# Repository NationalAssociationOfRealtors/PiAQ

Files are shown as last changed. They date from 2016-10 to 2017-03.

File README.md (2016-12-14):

#PiAQ - Open Source Indoor Air Quality Sensor
An open hardware and software indoor air quality Raspberry Pi HAT provided by the [National Association of REALTORS](http://realtor.org) and [CRT Labs](https://crtlabs.org).

The board comes in two form factors. One dedicated for the Raspberry Pi - [PiAQ](http://piaq.io)

<p align="center">
  <a href="http://piaq.io">CRT Sensor Board</a>
</p>

Measurement Points:

* Temperature (SHT31)
* Relative Humidity (SHT31)
* VOC (Volatile Organic Compounds) (IAQ Core)
* Derived CO2 (IAQ Core)
* Barometric Pressure (MPL3115A2)
* Light Intensity (TSL2561)
* CO Concentration (MiCS-4154)
* NO2 Concentration (MiCS-4154)
* Sound Intensity (ADMP401)

Connectivity:

* FSK (RFM69HW 433/915MHz)
* WiFi (Particle Photon)
* Cellular (Particle Electron) (Coming soon)
* LoRa (Coming Soon)

License:
Apache License Version 2.0

For information on the standalone air quality sensor, <a href="https://github.com/NationalAssociationOfRealtors/IndoorAirQualitySensor">click here.
<p align="center">
  CRT Sensor Board
</p>
</a>

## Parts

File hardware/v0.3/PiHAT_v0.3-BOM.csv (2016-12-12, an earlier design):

Qty | Value | Device | Package | Parts | Description | MPN
3 |  | LEDCHIPLED_0805 | CHIPLED_0805 | LED1- LED2- LED3 | LED | LTST-C170TBKT
8 | 0.1uF | CAP0805 | 805 | C3- C4- C5- C7- C10- C11- C12- C15 | Capacitor | CC0603KRX7R7BB104
1 | 1.5K | RESISTOR0805-RES | 805 | R3 | Resistor | RT0805BRD071K5L
2 | 100K | RESISTOR0805-RES | 805 | R8- R9 | Resistor | RC0805FR-07100KL
1 | 100pF | CAP0805 | 805 | C2 | Capacitor | CC0805JRNPO9BN101
5 | 10K | RESISTOR0805-RES | 805 | R1- R5- R6- R7- R13 | Resistor | RC0805JR-0710KL
1 | 16MHZ | RESONATOR16MHZ | RESONATOR-SMD | Y1 | Resonator | CSTCE16M0V53-R0
1 | 1uF | CAP0805 | 805 | C9 | Capacitor | CC0805KKX7R7BB105
1 | 4.7uF | CAP0805 | 805 | C8 | Capacitor | CC0805KKX5R8BB475
3 | 47 | RESISTOR0805-RES | 805 | R2- R4- R10 | Resistor | RC0805JR-0747RL
1 | ADMP401 | ADMP401 | ADMP401 | U6 | Omnidirection bottom-port MEMS microphone | INMP401ACEZ-R7
1 | ATMEGA328P | ATMEGA328P_TQFP | TQFP32-08 | U1 | MCU | ATMEGA328PB-AU
1 | BMP280 | BMP280 | BMP280 | IC1 | Barometric pressure sensor | BMP280
1 | CCS811 | CCS811-I2C | LGA | U8 | Digital Gas Sensor | CCS811
1 | OPA344 | OPA344 | SOT23-5 | U3 | Single gate rail-to-rail output op-amp. Inputs extend 300mV past rails. | OPA344NA/3K
1 | SHT31/35 | SHT31-DIS | SHT3X | U7 | Temperature and Humidity | SHT31-DIS-B
1 | TAC_SWITCHSMD | TAC_SWITCHSMD | TACTILE-SWITCH-SMD | RESET | Momentary Switch | PTS525SM15SMTR2 LFS
1 | TSL2561 | TSL2561FN | FN-6 | U2 | TSL2561 illumination sensor | TSL2561FN

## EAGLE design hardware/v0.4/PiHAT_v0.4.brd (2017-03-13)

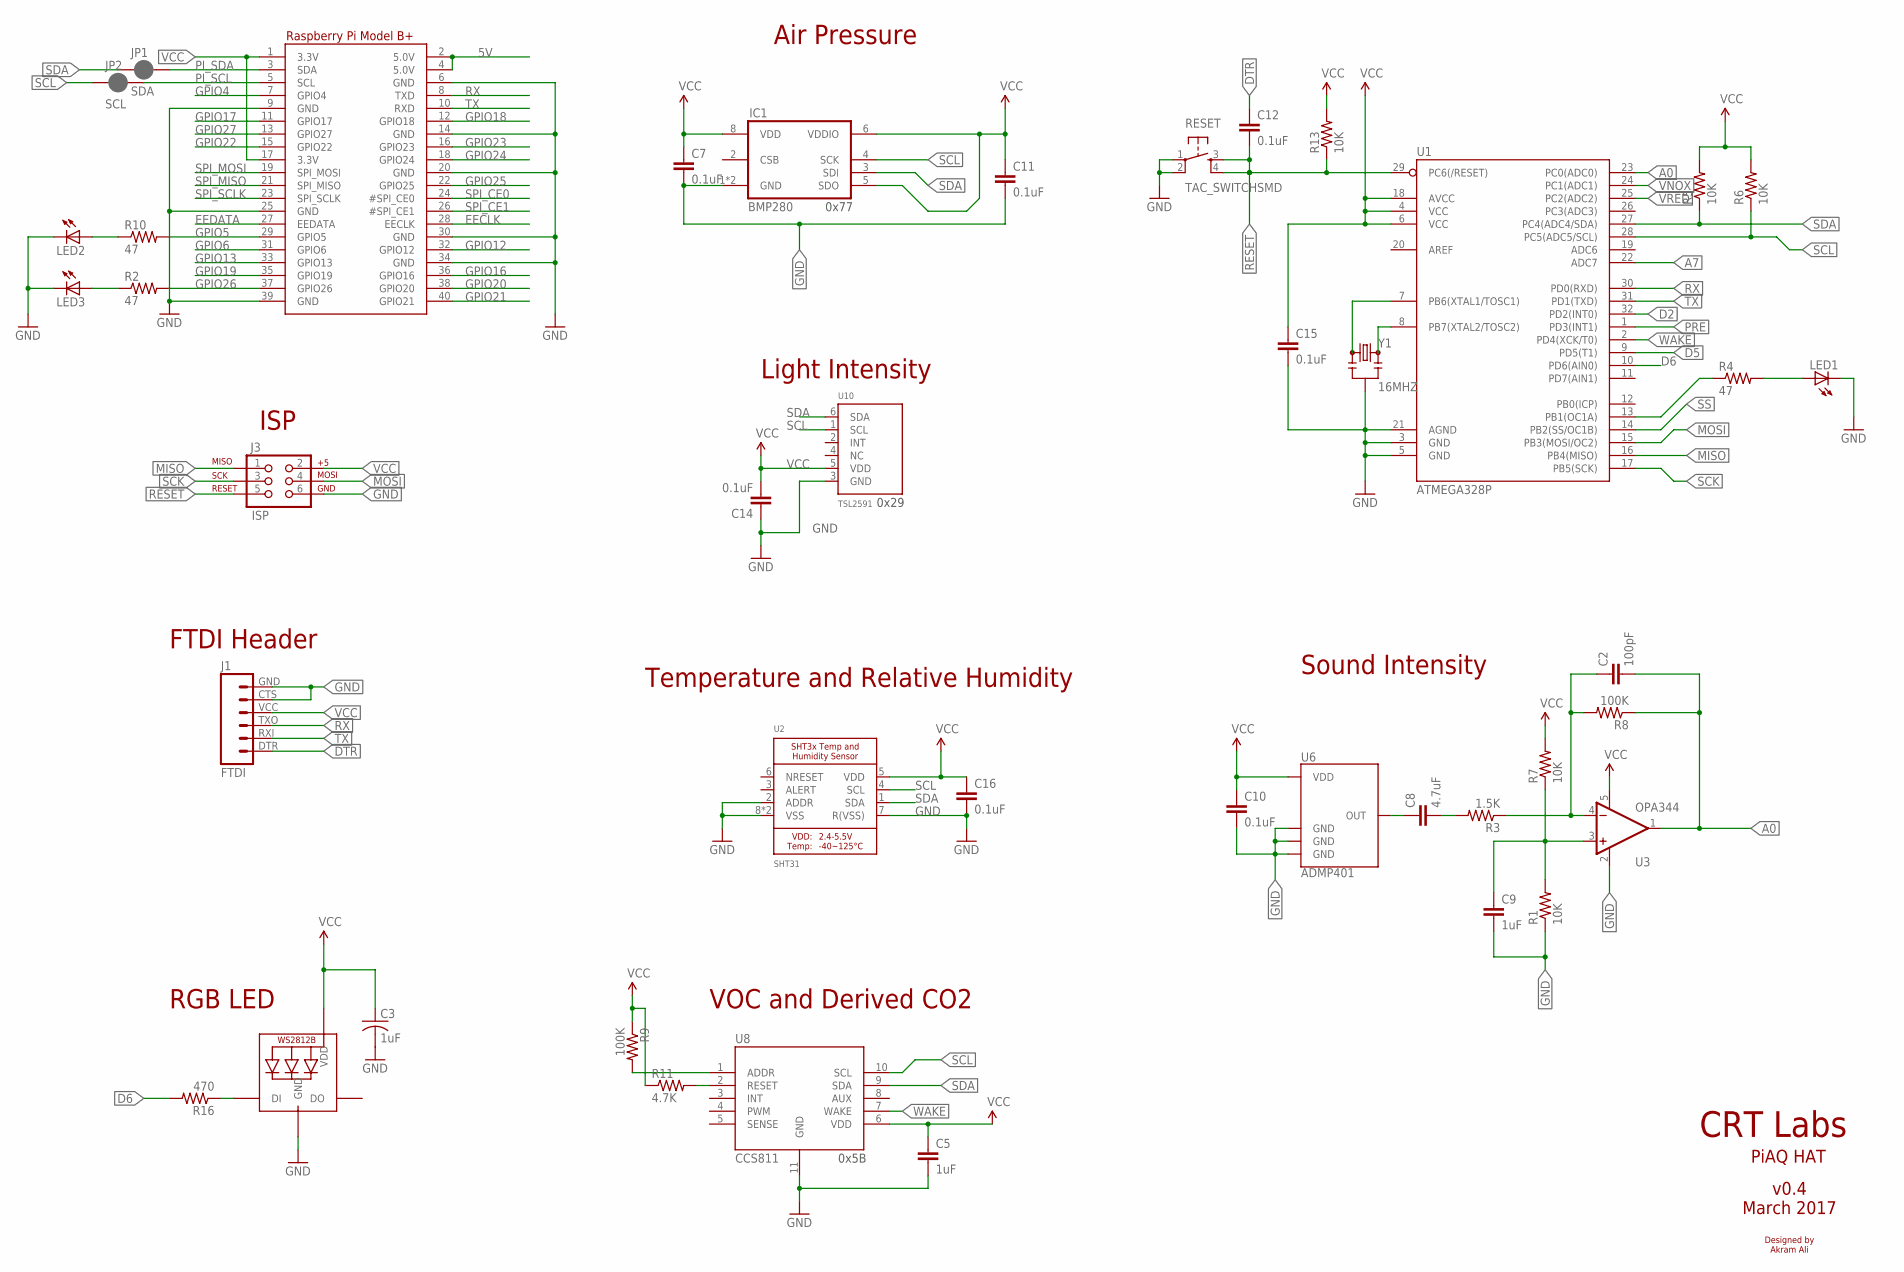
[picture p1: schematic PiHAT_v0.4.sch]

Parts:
C2: 100pF; 0805; MPN CC0805JRNPO9BN101
C3: 1uF; C0603K; MPN CC0805ZRY5V8BB105
C5: 1uF; 0805; MPN CC0603KRX7R7BB104
C7, C10, C11, C12, C15: 0.1uF; 0805; MPN CC0603KRX7R7BB104
C8: 4.7uF; 0805; MPN CC0805KKX5R8BB475
C9: 1uF; 0805; MPN CC0805KKX7R7BB105
C14, C16: 0.1uF; 0805; MPN CC0805KRX7R9BB104
IC1: BMP280; MPN BMP280
J1: FTDI; FTDI_BASIC
J3: ISP; 2X3
JP1: SDA; PAD-JUMPER-2-NC_BY_PASTE_YES_SILK_FULL_BOX
JP2: SCL; PAD-JUMPER-2-NC_BY_PASTE_YES_SILK_FULL_BOX
LED1, LED2, LED3: LEDCHIPLED_0805; CHIPLED_0805; MPN LTST-C170TBKT
R1, R5, R6, R7, R13: 10K; 0805; MPN RC0805JR-0710KL
R2, R4, R10: 47; 0805; MPN RC0805JR-0747RL
R3: 1.5K; 0805; MPN RT0805BRD071K5L
R8, R9: 100K; 0805; MPN RC0805FR-07100KL
R11: 4.7K; 0805; MPN RC0805FR-07100KL
R16: 470; R0603; MPN RC0805FR-07470RL
RESET: TAC_SWITCHSMD; TACTILE-SWITCH-SMD; MPN PTS525SM15SMTR2 LFS
RGBLED: WS2812B3535; LED3535; MPN SK6812 mini
RPI1: RASPBERRYPI_BPLUS_HATSLOTS; PI_HAT_SLOTS
U1: ATMEGA328P; TQFP32-08; MPN ATMEGA328PB-AU
U2: SHT31; SHT3X; MPN SHT35-DIS-B
U3: OPA344; SOT23-5; MPN OPA344NA/3K
U6: ADMP401; MPN INMP401ACEZ-R7
U8: CCS811; LGA; MPN CCS811
U10: TSL2591; DFN6_TAOS; MPN TSL25911FN
Y1: 16MHZ; RESONATOR-SMD; MPN CSTCE16M0V53-R0

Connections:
5V: RPI1.2 (5.0V), RPI1.4 (5.0V)
A0: C2.2, R8.1, U1.23 (PC0(ADC0)), U3.1 (OUT)
A7: U1.22 (ADC7)
D2: U1.32 (PD2(INT0))
D5: U1.9 (PD5(T1))
D6: R16.2, U1.10 (PD6(AIN0))
DTR: C12.1, J1.DTR (1)
EECLK: RPI1.28 (EECLK)
EEDATA: RPI1.27 (EEDATA)
GND: C3.2, C5.2, C7.2, C9.2, C10.2, C11.2, C14.1, C15.2, C16.2, IC1.1 (GND), IC1.7 (GND), J1.CTS (5), J1.GND (6), J3.6, LED1.C, LED2.C, LED3.C, R1.1, RESET.1, RESET.2, RGBLED.4 (GND), RPI1.6 (GND), RPI1.9 (GND), RPI1.14 (GND), RPI1.20 (GND), RPI1.25 (GND), RPI1.30 (GND), RPI1.34 (GND), RPI1.39 (GND), U1.3 (GND), U1.5 (GND), U1.21 (AGND), U2.2 (ADDR), U2.7 (R(VSS)), U2.8 (VSS), U2.THERMAL (VSS), U3.2 (V-), U6.2 (GND), U6.4 (GND), U6.6 (GND), U8.11 (GND), U10.3 (GND), Y1.2
GPIO4: RPI1.7 (GPIO4)
GPIO5: R10.2, RPI1.29 (GPIO5)
GPIO6: RPI1.31 (GPIO6)
GPIO12: RPI1.32 (GPIO12)
GPIO13: RPI1.33 (GPIO13)
GPIO16: RPI1.36 (GPIO16)
GPIO17: RPI1.11 (GPIO17)
GPIO18: RPI1.12 (GPIO18)
GPIO19: RPI1.35 (GPIO19)
GPIO20: RPI1.38 (GPIO20)
GPIO21: RPI1.40 (GPIO21)
GPIO22: RPI1.15 (GPIO22)
GPIO23: RPI1.16 (GPIO23)
GPIO24: RPI1.18 (GPIO24)
GPIO25: RPI1.22 (GPIO25)
GPIO26: R2.2, RPI1.37 (GPIO26)
GPIO27: RPI1.13 (GPIO27)
MISO: J3.1, U1.16 (PB4(MISO))
MOSI: J3.4, U1.15 (PB3(MOSI/OC2))
unnamed: LED3.A, R2.1
unnamed: R4.1, U1.13 (PB1(OC1A))
unnamed: LED1.A, R4.2
unnamed: U1.8 (PB7(XTAL2/TOSC2)), Y1.3
unnamed: U1.7 (PB6(XTAL1/TOSC1)), Y1.1
unnamed: LED2.A, R10.1
unnamed: C8.1, U6.1 (OUT)
unnamed: R11.2, U8.2 (RESET)
unnamed: C8.2, R3.2
unnamed: C2.1, R3.1, R8.2, U3.4 (-IN)
unnamed: C9.1, R1.2, R7.1, U3.3 (+IN)
unnamed: R16.1, RGBLED.1 (DI)
unnamed: R9.2, U8.1 (ADDR)
PI_SCL: JP2.2, RPI1.5 (SCL)
PI_SDA: JP1.2, RPI1.3 (SDA)
PRE: U1.1 (PD3(INT1))
RESET: C12.2, J3.5, R13.1, RESET.3, RESET.4, U1.29 (PC6(/RESET))
RX: J1.TXO (3), RPI1.8 (TXD), U1.30 (PD0(RXD))
SCK: J3.3, U1.17 (PB5(SCK))
SCL: IC1.4 (SCK), JP2.1, R6.1, U1.28 (PC5(ADC5/SCL)), U2.4 (SCL), U8.10 (SCL), U10.1 (SCL)
SDA: IC1.3 (SDI), JP1.1, R5.1, U1.27 (PC4(ADC4/SDA)), U2.1 (SDA), U8.9 (SDA), U10.6 (SDA)
SPI_CE0: RPI1.24 (#SPI_CE0)
SPI_CE1: RPI1.26 (#SPI_CE1)
SPI_MISO: RPI1.21 (SPI_MISO)
SPI_MOSI: RPI1.19 (SPI_MOSI)
SPI_SCLK: RPI1.23 (SPI_SCLK)
SS: U1.14 (PB2(SS/OC1B))
TX: J1.RXI (2), RPI1.10 (RXD), U1.31 (PD1(TXD))
VCC: C3.1, C5.1, C7.1, C10.1, C11.1, C14.2, C15.1, C16.1, IC1.5 (SDO), IC1.6 (VDDIO), IC1.8 (VDD), J1.VCC (4), J3.2, R5.2, R6.2, R7.2, R9.1, R11.1, R13.2, RGBLED.2 (VDD), RPI1.1 (3.3V), RPI1.17 (3.3V), U1.4 (VCC), U1.6 (VCC), U1.18 (AVCC), U2.5 (VDD), U3.5 (V+), U6.5 (VDD), U8.6 (VDD), U10.5 (VDD)
VNOX: U1.24 (PC1(ADC1))
VRED: U1.25 (PC2(ADC2))
WAKE: U1.2 (PD4(XCK/T0)), U8.7 (WAKE)

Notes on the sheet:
VOC and Derived CO2
Air Pressure
Sound Intensity
Temperature and Relative Humidity
ISP
CRT Labs
PiAQ HAT
v0.4 March 2017
Designed by Akram Ali
0x5B
FTDI Header
0x77
Light Intensity
0x29
RGB LED

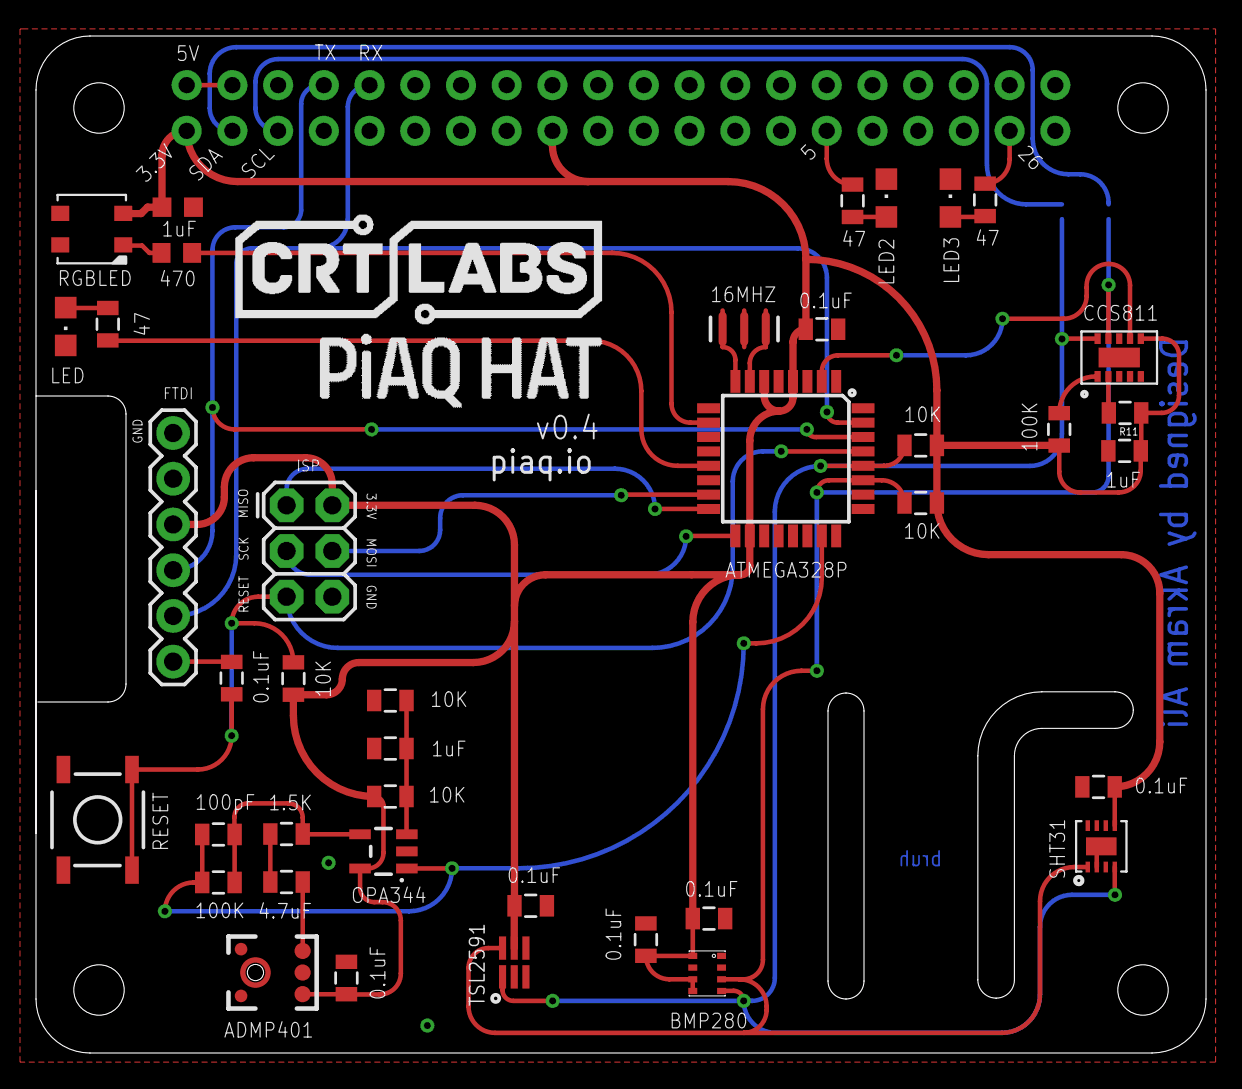
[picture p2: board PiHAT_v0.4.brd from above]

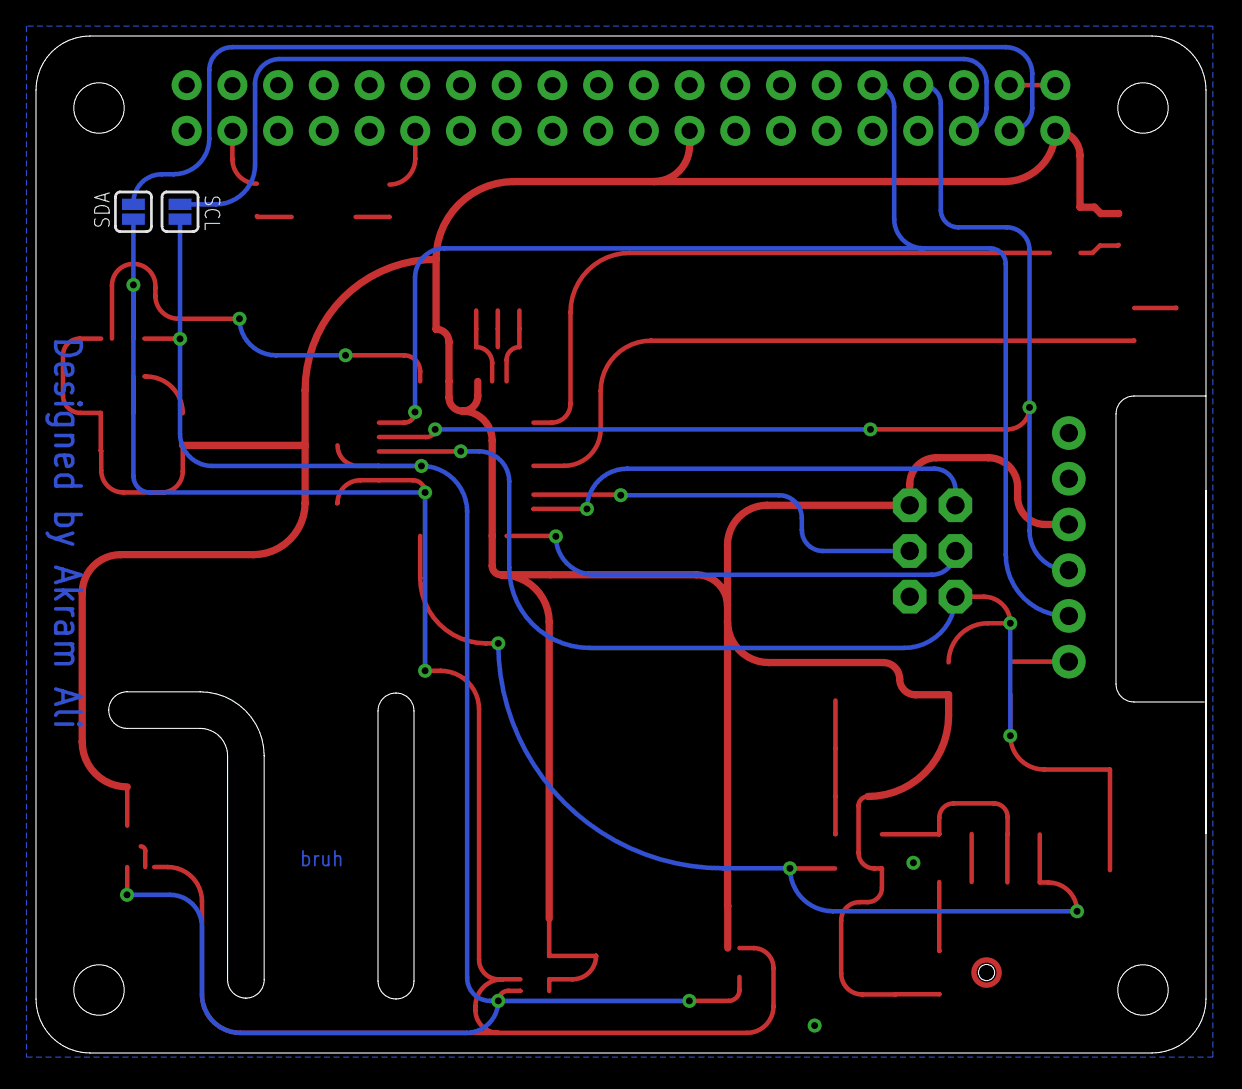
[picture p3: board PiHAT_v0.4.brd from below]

Board: 2 copper layers, 65.0 x 56.5 mm, 43 parts (2 on the bottom side), 32 nets.

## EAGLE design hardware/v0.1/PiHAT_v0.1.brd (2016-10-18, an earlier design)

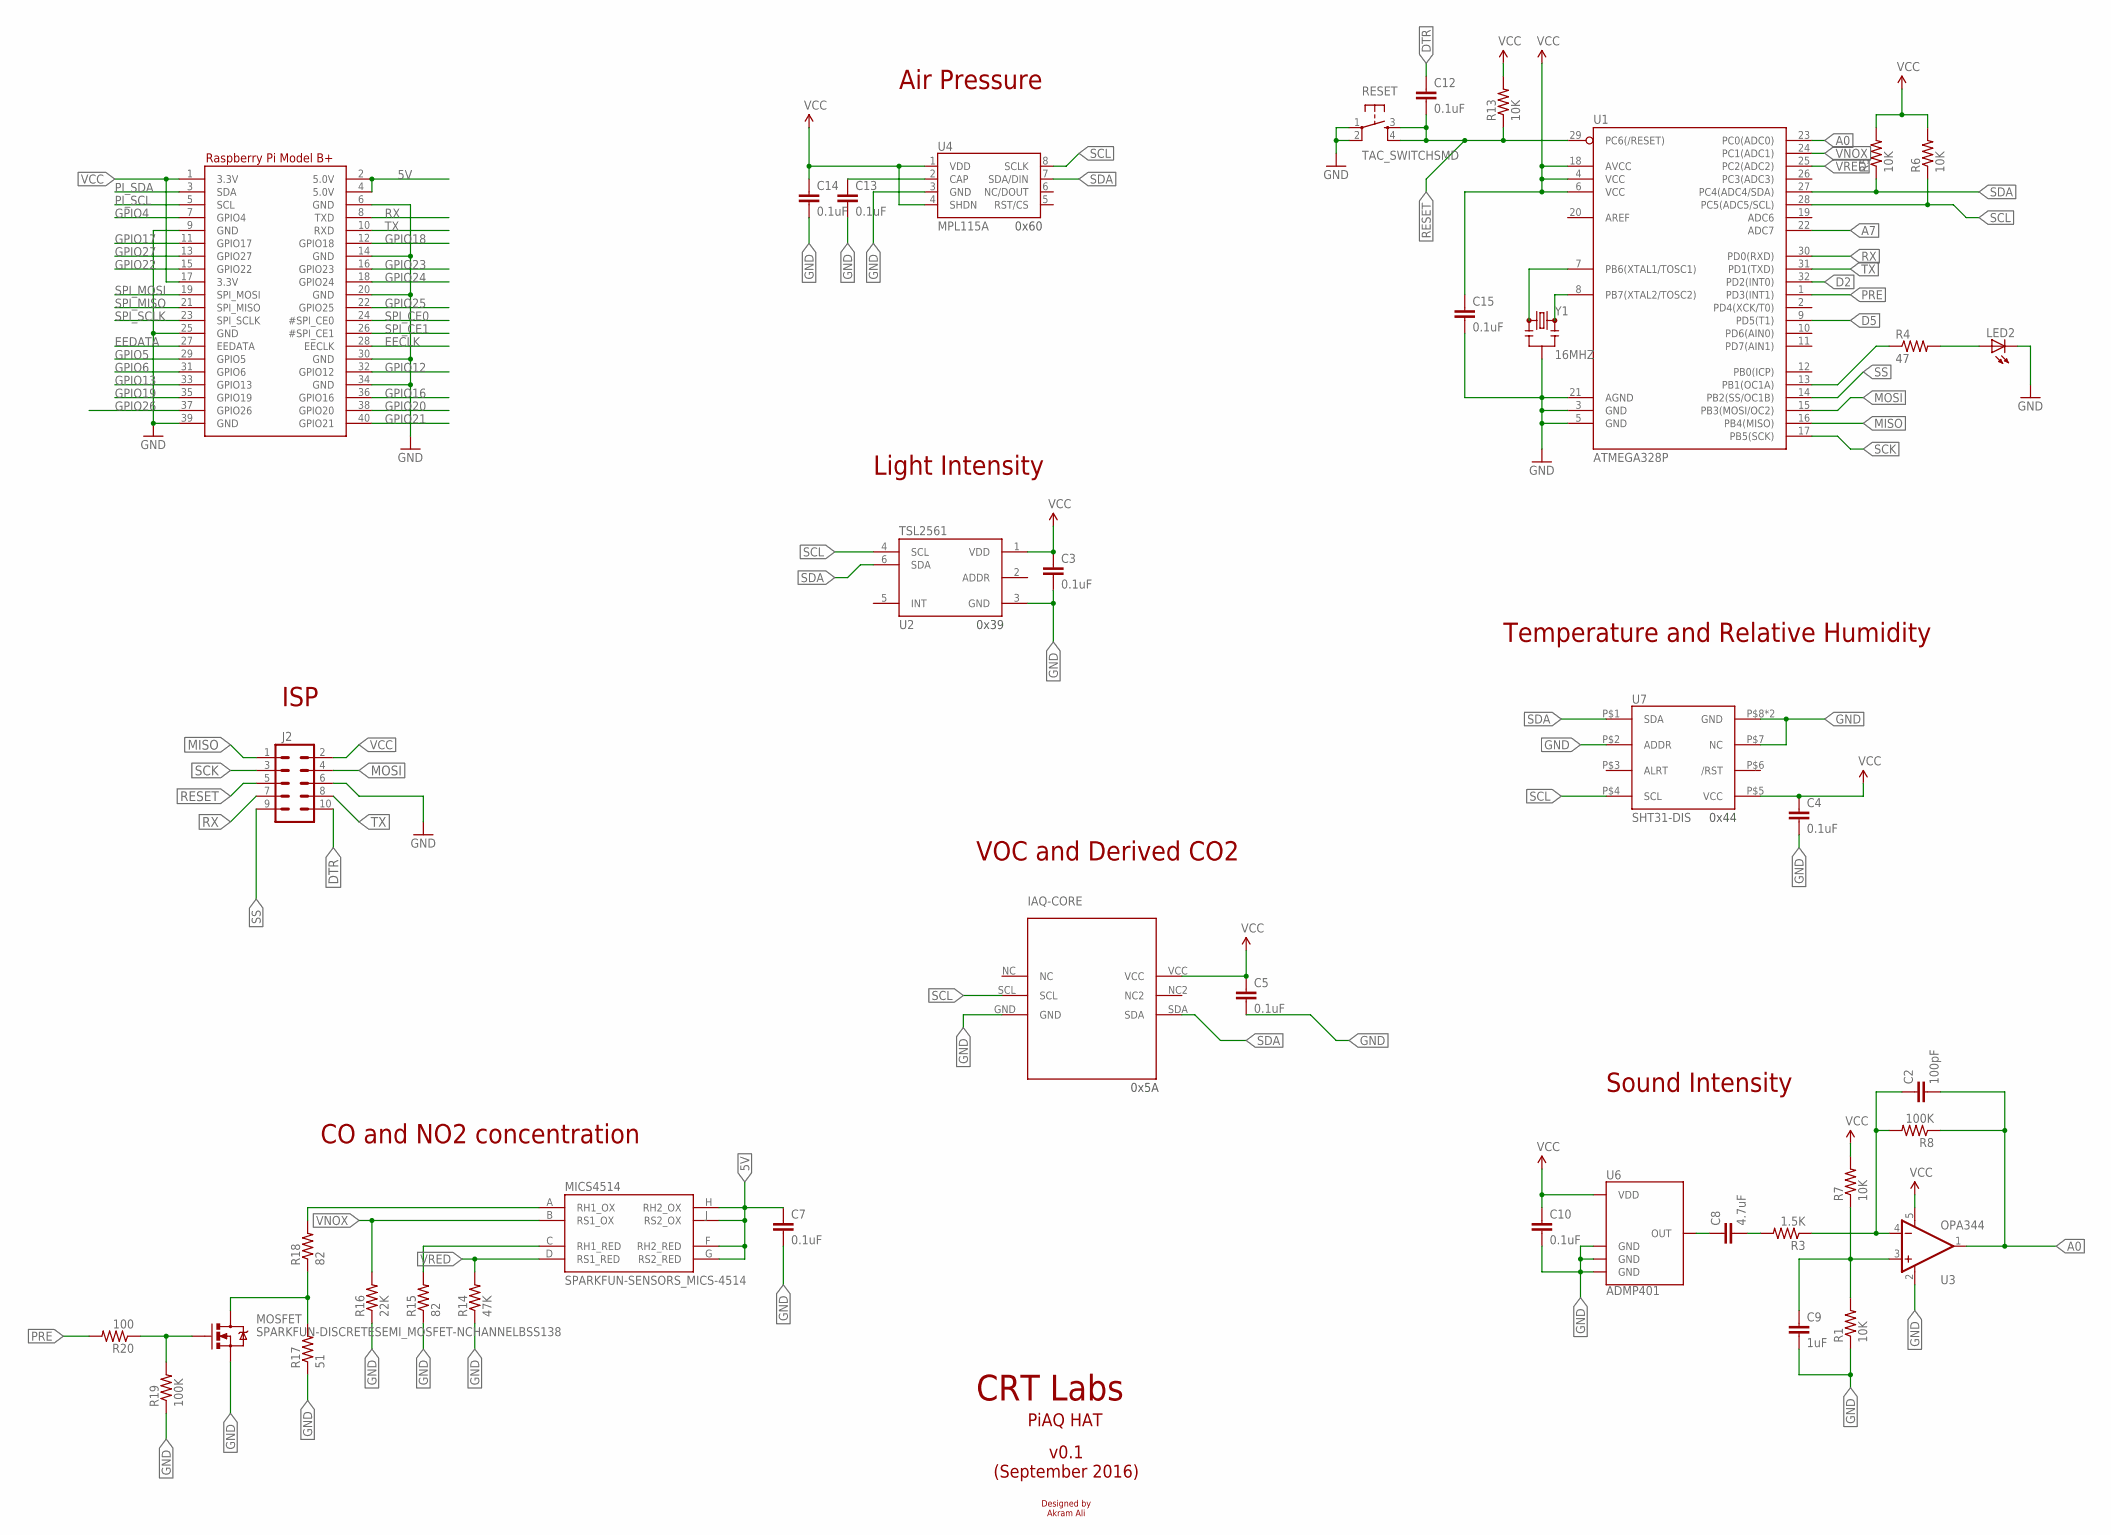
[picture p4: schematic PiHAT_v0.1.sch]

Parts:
C2: 100pF; 0805; DIGIKEY# 311-1111-1-ND
C3, C4, C5, C7, C10, C12, C13, C14, C15: 0.1uF; 0805; DIGIKEY# 311-1088-1-ND
C8: 4.7uF; 0805; DIGIKEY# 311-1871-1-ND
C9: 1uF; 0805; DIGIKEY# 311-1365-1-ND
IAQ-CORE: IAQ-CORE; MPN IAQ CORE; DIGIKEY# IAQ-CORE C-ND
J2: M05X2PTH; AVR_ICSP; DIGIKEY# S6105-ND
LED2: LEDCHIPLED_0805; CHIPLED_0805; DIGIKEY# 475-1196-1-ND
MICS4514: SPARKFUN-SENSORS_MICS-4514; SPARKFUN-SENSORS_MICS_10-SMD
MOSFET: SPARKFUN-DISCRETESEMI_MOSFET-NCHANNELBSS138; SPARKFUN-DISCRETESEMI_SOT23-3; DIGIKEY# BSS138-FDICT-ND
R1, R5, R6, R7, R13: 10K; 0805; DIGIKEY# 311-10KARCT-ND
R3: 1.5K; 0805; DIGIKEY# YAG1814CT-ND
R4: 47; 0805; DIGIKEY# 311-47ARCT-ND
R8: 100K; 0805; DIGIKEY# 541-82.0CCT-ND
R14: 47K; 0805; DIGIKEY# RHM47KKCT-ND
R15, R18: 82; 0805; DIGIKEY# 541-82.0CCT-ND
R16: 22K; 0805; DIGIKEY# 311-22KARCT-ND
R17: 51; 0805; DIGIKEY# RHM51KCT-ND
R19: 100K; 0805; DIGIKEY# 311-100KCRCT-ND
R20: 100; 0805; DIGIKEY# 311-100CRCT-ND
RESET: TAC_SWITCHSMD; TACTILE-SWITCH-SMD; DIGIKEY# CKN9104CT-ND
RPI1: RASPBERRYPI_BPLUS_HATSLOTS; PI_HAT_SLOTS
U1: ATMEGA328P; TQFP32-08; MPN ATMEGA328PB-AU; DIGIKEY# ATMEGA328P-AU-ND
U2: TSL2561; FN-6; MOUSER# 856-TSL2561T; DIGIKEY# TSL2561-FNCT-ND
U3: OPA344; SOT23-5; DIGIKEY# 296-41475-1-ND
U4: MPL115A; LGA8; DIGIKEY# MPL115A2-ND
U6: ADMP401; DIGIKEY# INMP401ACEZ-R7CT-ND
U7: SHT31-DIS; SHT3X; MPN SHT31-DIS-B; DIGIKEY# 1649-1011-1-ND
Y1: 16MHZ; RESONATOR-SMD; DIGIKEY# 490-1198-1-ND

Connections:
5V: C7.1, MICS4514.F (RH2_RED), MICS4514.G (RS2_RED), MICS4514.H (RH2_OX), MICS4514.J (RS2_OX), RPI1.2 (5.0V), RPI1.4 (5.0V)
A0: C2.2, R8.1, U1.23 (PC0(ADC0)), U3.1 (OUT)
A7: U1.22 (ADC7)
D2: U1.32 (PD2(INT0))
D5: U1.9 (PD5(T1))
DTR: C12.1, J2.10
EECLK: RPI1.28 (EECLK)
EEDATA: RPI1.27 (EEDATA)
GND: C3.2, C4.2, C5.2, C7.2, C9.2, C10.2, C13.2, C14.2, C15.2, IAQ-CORE.GND, J2.6, LED2.C, MOSFET.2 (S), R1.1, R14.1, R15.1, R16.1, R17.1, R19.1, RESET.1, RESET.2, RPI1.6 (GND), RPI1.9 (GND), RPI1.14 (GND), RPI1.20 (GND), RPI1.25 (GND), RPI1.30 (GND), RPI1.34 (GND), RPI1.39 (GND), U1.3 (GND), U1.5 (GND), U1.21 (AGND), U2.3 (GND), U3.2 (V-), U4.3 (GND), U6.2 (GND), U6.4 (GND), U6.6 (GND), U7.P$2 (ADDR), U7.P$7 (NC), U7.P$8 (GND), U7.PAD (GND), Y1.2
GPIO4: RPI1.7 (GPIO4)
GPIO5: RPI1.29 (GPIO5)
GPIO6: RPI1.31 (GPIO6)
GPIO12: RPI1.32 (GPIO12)
GPIO13: RPI1.33 (GPIO13)
GPIO16: RPI1.36 (GPIO16)
GPIO17: RPI1.11 (GPIO17)
GPIO18: RPI1.12 (GPIO18)
GPIO19: RPI1.35 (GPIO19)
GPIO20: RPI1.38 (GPIO20)
GPIO21: RPI1.40 (GPIO21)
GPIO22: RPI1.15 (GPIO22)
GPIO23: RPI1.16 (GPIO23)
GPIO24: RPI1.18 (GPIO24)
GPIO25: RPI1.22 (GPIO25)
GPIO26: RPI1.37 (GPIO26)
GPIO27: RPI1.13 (GPIO27)
MISO: J2.1, U1.16 (PB4(MISO))
MOSI: J2.4, U1.15 (PB3(MOSI/OC2))
unnamed: R4.1, U1.13 (PB1(OC1A))
unnamed: LED2.A, R4.2
unnamed: U1.8 (PB7(XTAL2/TOSC2)), Y1.3
unnamed: U1.7 (PB6(XTAL1/TOSC1)), Y1.1
unnamed: C8.1, U6.1 (OUT)
unnamed: MICS4514.A (RH1_OX), R18.2
unnamed: C8.2, R3.2
unnamed: C2.1, R3.1, R8.2, U3.4 (-IN)
unnamed: C9.1, R1.2, R7.1, U3.3 (+IN)
unnamed: C13.1, U4.2 (CAP)
unnamed: MICS4514.C (RH1_RED), R15.2
unnamed: MOSFET.3 (D), R17.2, R18.1
unnamed: MOSFET.1 (G), R19.2, R20.1
PI_SCL: RPI1.5 (SCL)
PI_SDA: RPI1.3 (SDA)
PRE: R20.2, U1.1 (PD3(INT1))
RESET: C12.2, J2.5, R13.1, RESET.3, RESET.4, U1.29 (PC6(/RESET))
RX: J2.7, RPI1.8 (TXD), U1.30 (PD0(RXD))
SCK: J2.3, U1.17 (PB5(SCK))
SCL: IAQ-CORE.SCL, R6.1, U1.28 (PC5(ADC5/SCL)), U2.4 (SCL), U4.8 (SCLK), U7.P$4 (SCL)
SDA: IAQ-CORE.SDA, R5.1, U1.27 (PC4(ADC4/SDA)), U2.6 (SDA), U4.7 (SDA/DIN), U7.P$1 (SDA)
SPI_CE0: RPI1.24 (#SPI_CE0)
SPI_CE1: RPI1.26 (#SPI_CE1)
SPI_MISO: RPI1.21 (SPI_MISO)
SPI_MOSI: RPI1.19 (SPI_MOSI)
SPI_SCLK: RPI1.23 (SPI_SCLK)
SS: J2.9, U1.14 (PB2(SS/OC1B))
TX: J2.8, RPI1.10 (RXD), U1.31 (PD1(TXD))
VCC: C3.1, C4.1, C5.1, C10.1, C14.1, C15.1, IAQ-CORE.VCC, J2.2, R5.2, R6.2, R7.2, R13.2, RPI1.1 (3.3V), RPI1.17 (3.3V), U1.4 (VCC), U1.6 (VCC), U1.18 (AVCC), U2.1 (VDD), U3.5 (V+), U4.1 (VDD), U4.4 (SHDN), U6.5 (VDD), U7.P$5 (VCC)
VNOX: MICS4514.B (RS1_OX), R16.2, U1.24 (PC1(ADC1))
VRED: MICS4514.D (RS1_RED), R14.2, U1.25 (PC2(ADC2))

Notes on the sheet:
Light Intensity
VOC and Derived CO2
Air Pressure
Sound Intensity
Temperature and Relative Humidity
ISP
CO and NO2 concentration
CRT Labs
PiAQ HAT
v0.1 (September 2016)
Designed by Akram Ali
0x39
0x60
0x5A
0x44

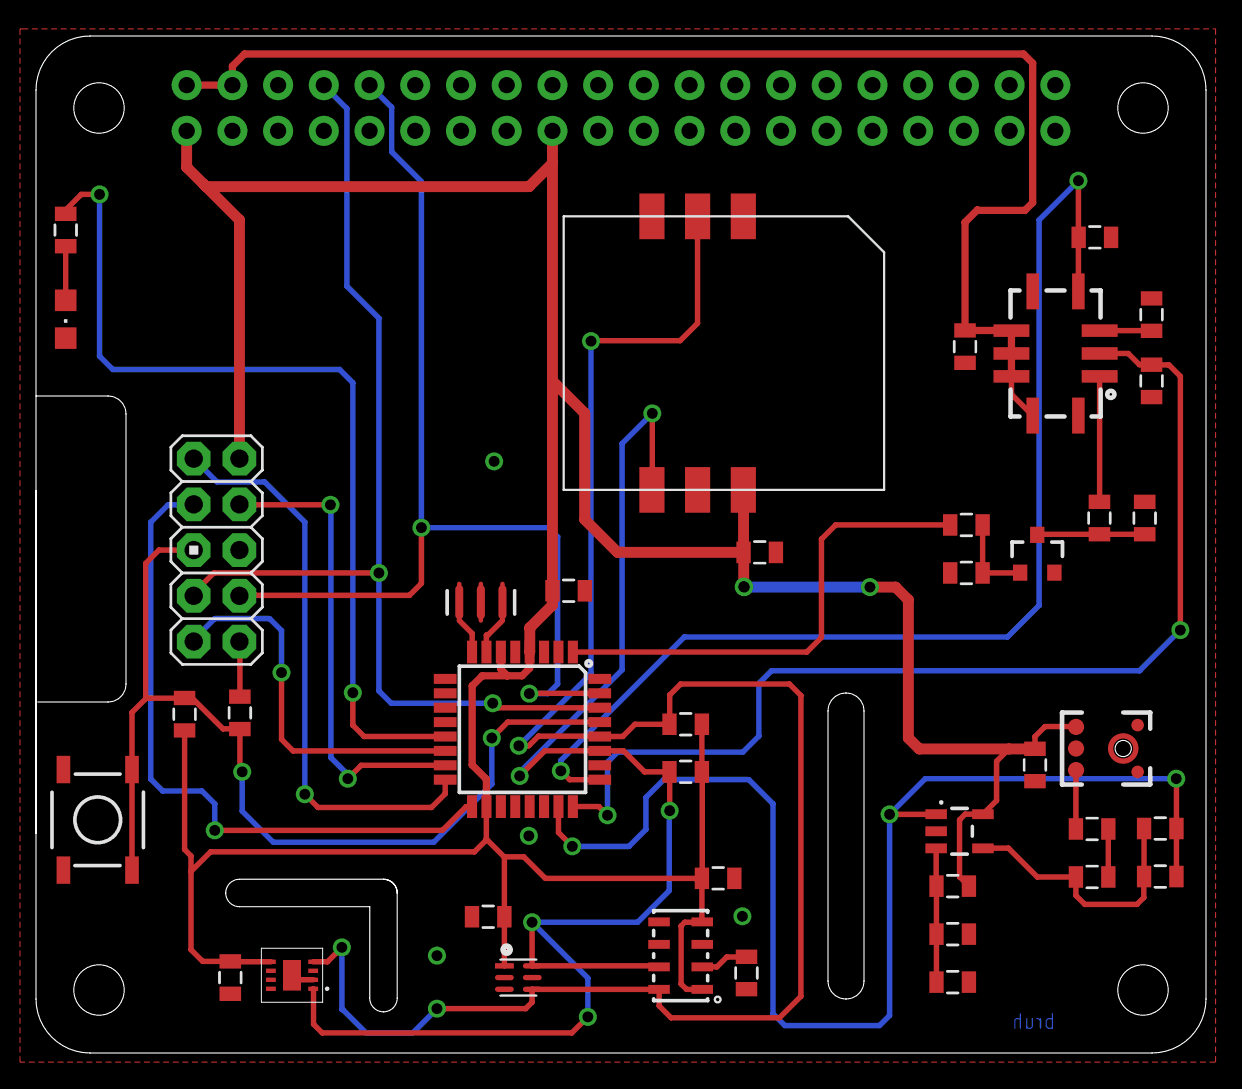
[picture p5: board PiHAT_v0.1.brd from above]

Board: 2 copper layers, 65.0 x 56.5 mm, 41 parts (0 on the bottom side), 30 nets.

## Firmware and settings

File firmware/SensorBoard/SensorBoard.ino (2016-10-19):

/*
  Sensor Board v0.2
  Measures Temperature, Relative Humidity, Light intensity,
  Air pressure (and derived altitude), Sound intensity,
  concentrations of CO, NO2, VOC (derived) and CO2 (derived)

  Currently untested: TSL2561 light sensor code
  Currently untested: ADMP401 mic code
  
  Designed at CRT Labs (July 2016)
  https://github.com/NationalAssociationOfRealtors/SensorBoard
  
  Modified: 8 September 2016
  by Akram Ali
 */

// define libraries
#include <Arduino.h>
#include <Wire.h>
#include "Adafruit_SHT31.h"
#include "SparkFunMPL3115A2.h"
#include <Adafruit_Sensor.h>
#include <Adafruit_TSL2561_U.h>

// define objects
MPL3115A2 myPressure;
Adafruit_SHT31 sht31 = Adafruit_SHT31();
Adafruit_TSL2561_Unified tsl = Adafruit_TSL2561_Unified(TSL2561_ADDR_FLOAT, 12345);

// define IAQ core global variables
#define iaqaddress 0x5A
uint16_t predict;
uint8_t statu;
int32_t resistance;
uint16_t tvoc;

// define MICS-4514 global variables
#define PRE_PIN          8
#define VNOX_PIN         A1
#define VRED_PIN         A2
#define PRE_HEAT_SECONDS 10
int vnox_value = 0;
int vred_value = 0;

// define TSL2561 global variables
long lux;

void setup()
{
  Serial.begin(115200);
  Serial.println("Setup");

  pinMode(9, OUTPUT);  // pin 9 controls LED
  pinMode(5, OUTPUT);   // pin 5 controls power to all sensors
  digitalWrite(5, HIGH);  // turn all sensors on
  delay(10);

  pinMode(PRE_PIN, OUTPUT);  // set preheater pin for mics4514 gas sensor
  Serial.print("MICS-4514 Preheating...");
  // Wait for preheating
  digitalWrite(PRE_PIN, 1);
  delay(PRE_HEAT_SECONDS * 1000);
  digitalWrite(PRE_PIN, 0);
  Serial.println("Done");
  
}

// the loop function runs over and over again forever
void loop()
{
  digitalWrite(9, HIGH);   // turn the LED on (HIGH is the voltage level)
  delay(1000);              // wait for a second
  digitalWrite(9, LOW);    // turn the LED off by making the voltage LOW
  
  Serial.println("---------------------");
  
  // ADMP401 mic for sound level
  Serial.print("Sound Level: ");
  Serial.print(analogRead(A0));  // read sound levels
  Serial.println();


  // TSL2561 light sensor
  tsl.begin(); 
  tsl.enableAutoRange(true);
  //tsl.setIntegrationTime(TSL2561_INTEGRATIONTIME_13MS);      /* fast but low resolution */
  tsl.setIntegrationTime(TSL2561_INTEGRATIONTIME_101MS);  /* medium resolution and speed   */
  // tsl.setIntegrationTime(TSL2561_INTEGRATIONTIME_402MS);  /* 16-bit data but slowest conversions */
  sensors_event_t event;
  tsl.getEvent(&event);
  if (event.light)
    lux = event.light;
  else
    lux = -1;
  Serial.print("Light intensity (lux): ");
  Serial.println(lux);
  
  // MICS 4514 CO/NO2 gas sensor
  // Read analog values, print them out, and wait
  vnox_value = analogRead(VNOX_PIN);
  vred_value = analogRead(VRED_PIN);
  Serial.print("Vnox: ");
  Serial.print(vnox_value, DEC);
  Serial.print(" Vred: ");
  Serial.println(vred_value, DEC);
  readCO();
  readNO2();

  
  // MPL3115A2 air pressure sensor
  myPressure.begin(); // Get pressure sensor online
  //Configure the sensor
  //myPressure.setModeAltimeter(); // Measure altitude above sea level in meters
  myPressure.setModeBarometer(); // Measure pressure in Pascals from 20 to 110 kPa
  
  myPressure.setOversampleRate(7); // Set Oversample to the recommended 128
  myPressure.enableEventFlags(); // Enable all three pressure and temp event flags 
  delay(10);
  
  float pressure = myPressure.readPressure();
  Serial.print("MPL3115A2 Pressure(Pa): ");
  Serial.println(pressure, 2);

  float temperature = myPressure.readTempF();
  Serial.print("MPL3115A2 Temp(f): ");
  Serial.println(temperature, 2);

  //const int station_elevation_ft = 5374; //Must be obtained with a GPS unit
  //float station_elevation_m = station_elevation_ft * 0.3048; //I'm going to hard code this
  const int station_elevation_m = 1638; //Accurate for the roof on my house
  //1 pascal = 0.01 millibars
  pressure /= 100; //pressure is now in millibars

  float part1 = pressure - 0.3; //Part 1 of formula
  
  const float part2 = 8.42288 / 100000.0;
  float part3 = pow((pressure - 0.3), 0.190284);
  float part4 = (float)station_elevation_m / part3;
  float part5 = (1.0 + (part2 * part4));
  float part6 = pow(part5, (1.0/0.190284));
  float altimeter_setting_pressure_mb = part1 * part6; //Output is now in adjusted millibars
  float baroin = altimeter_setting_pressure_mb * 0.02953;

  Serial.print("MPL3115A2 Altimeter setting InHg: ");
  Serial.println(baroin, 2);

  
  // SHT31 T/RH sensor 
  sht31.begin(0x44);
  Serial.print("SHT31 Temperature: ");
  Serial.println(sht31.readTemperature());
  Serial.print("SHT31 Humidity: ");
  Serial.println(sht31.readHumidity());
  

  // IAQ core
  Wire.requestFrom(iaqaddress, 9);
  predict = (Wire.read()<< 8 | Wire.read()); 
  statu = Wire.read();
  resistance = (Wire.read()& 0x00)| (Wire.read()<<16)| (Wire.read()<<8| Wire.read());
  tvoc = (Wire.read()<<8 | Wire.read());
  checkStatus();
  
  Serial.print("CO2 concentration:");
  Serial.println(predict);
  //Serial.print("IAQ core Status: ");
  //Serial.println(statu, HEX);
  Serial.print("IAQ core Resistance: ");
  Serial.println(resistance);
  Serial.print("TVoC concentration: ");
  Serial.println(tvoc);

  
  Serial.println();
  
  //digitalWrite(5, LOW);  // turn sensors off
  delay(5000);
}



void checkStatus()
{
  if(statu == 0x10)
  {
    Serial.println("IAQ Core Warming up...");
  }
  else if(statu == 0x00)
  {
    Serial.println("IAQ Core Ready");  
  }
  else if(statu == 0x01)
  {
    Serial.println("IAQ Core Busy");  
  }
  else if(statu == 0x80)
  {
    Serial.println("IAQ Core Error");  
  }
  else
  Serial.println("No Status, check IAQ Core");  
}



float readCO()
{
  float adc = analogRead(VNOX_PIN);
  float Rs = 47000.0/(1023.0/adc);
  float R0 = 82000.0;
  float ratio = Rs/R0;
  float concentration = ((-181.4)*log(ratio))-97.469;
  Serial.print("CO concentration (ppb): ");
  //Serial.println(adc);
  //Serial.println(Rs);
  //Serial.println(R0);
  //Serial.println(ratio);
  if(concentration>0)
  {
    Serial.println(concentration);
    return concentration;
  }
  else
  {
    Serial.println("0");
    return 0;
  }
}

float readNO2()
{
  float adc = analogRead(VRED_PIN);
  float Rs = 22000.0/(1023.0/adc);
  float R0 = 350.0;
  float ratio = Rs/R0;
  float concentration = (124.28*log(ratio))-270.37;
  Serial.print("NO2 concentration (ppb): ");
  //Serial.println(adc);
  //Serial.println(Rs);
  //Serial.println(R0);
  //Serial.println(ratio);
  if(concentration>0)
  {
    Serial.println(concentration);
    return concentration;
  }
  else
  {
    Serial.println("0");
    return 0;
  }
}

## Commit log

2016-10-18 moving piaq to standalone repo
    leaving sensor board in previous repo
    [PiHAT_BOM.csv, PiHAT_v0.1.brd, PiHAT_v0.1.sch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]
2016-10-19 linking to v2 of board from osh park
2016-10-19 removing documents related to sensor board
    [IAQ-Case-bottom.stl, IAQ-Case.scad, IAQ-Case.stl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]
2016-10-19 removing sensor board firmware
2016-12-09 PiAQ v0.3 - design update
    Added CCS811 CO2/VOC sensor (replaced IAQ core)
    Added BMP280 pressure sensor (replaced MPL3115A2)
    Connected I2C pins from ATmega328P to RPi I2C pins
    Rewired everything using rounded traces
    [PiHAT_v0.3.brd, PiHAT_v0.3.sch]
2016-12-09 Some trace adjustments
    [PiHAT_v0.3.brd, PiHAT_v0.3.sch]
2016-12-09 Added jumpers on the I2C line
    Jumpers between Pi's SDA and SCL lines and ATmega's SDA and SCL lines
    [PiHAT_v0.3.brd, PiHAT_v0.3.sch]
2016-12-09 Changed silkscreen to tPlace/bPlace layers
    from 121/122 to 21/22
    [PiHAT_v0.3.brd]
2016-12-12 BOM adjustments
    [PiHAT_v0.3.brd, PiHAT_v0.3.sch]
2016-12-12 Updated all attributes for BOM
    Fixed digikey and mouser numbers
    [PiHAT_v0.3.brd, PiHAT_v0.3.sch]
2016-12-12 Added gerber files
    [PiHAT_v0.3.GBL, PiHAT_v0.3.GBO, PiHAT_v0.3.GBP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]
2016-12-12 Updated LED attributes
    Changed MPN from 0603 to 0805 part
    [PiHAT_v0.3.brd, PiHAT_v0.3.sch]
2016-12-12 adding compressed gerber files
2016-12-12 adding BOM
    [PiHAT_v0.3-BOM.csv]
2016-12-12 Removed Digikey and Mouser numbers to avoid confusion
    [PiHAT_v0.3.brd, PiHAT_v0.3.sch]
2017-03-07 v0.4 added [WIP]
    [PiHAT_v0.4.brd, PiHAT_v0.4.sch]
2017-03-07 v0.4 - update
    Relocated SHT31/35 sensor location to be on a 'cooler' spot over the Pi
    Added extra rullup resistor on CCS811 to make it stable during startups
    trace adjustments
    [PiHAT_v0.4.brd]
2017-03-13 Adjusted silkscreen
    [PiHAT_v0.4.brd, PiHAT_v0.4.sch]
2017-03-13 Added RGB LED
    - RGB LED on pin 6
    - Rearragned other LED on pin 9 and adjusted trace
    [PiHAT_v0.4.brd, PiHAT_v0.4.sch]

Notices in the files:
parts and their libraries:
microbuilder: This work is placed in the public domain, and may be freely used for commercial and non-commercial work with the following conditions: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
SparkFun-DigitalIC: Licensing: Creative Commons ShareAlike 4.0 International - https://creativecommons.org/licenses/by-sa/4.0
